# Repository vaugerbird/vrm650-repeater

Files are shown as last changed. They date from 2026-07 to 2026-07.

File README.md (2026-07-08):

# vrm650-repeater

A repository of docs on how to build a DMR repeater using VRM650 radios

### Table of contents:

1. [Parts and materials](./docs/parts.md)
2. [Assembly](./docs/assy.md)
3. [Wiring](./docs/wiring.md)
4. [Configuration](./docs/config.md)
5. [Testing and Tuning](./docs/tune.md)

---

## What this guide is (not):

I am providing this set of instructions as a guideline, not an explicit set of requirements. There are many things I could have done better on and changes or improvements are welcome and encouraged. 

That being said, all materials, instructions, and images here will be following my journey in building a repeater inside of a (very) cheap PC server case from Amazon, while trying to spend the least amount of money possible. Other case/housing configurations can and will work great, but this was the most convenient for me. 

### Begin the guide: [Parts and Materials](/docs/parts.md)

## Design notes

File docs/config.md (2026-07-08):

# Configuration
---
### Previous Page: [Wiring](./wiring.md)
---

## Coming Soon!

---
### Next Page: [Testing and Tuning](./tuning.md)
---

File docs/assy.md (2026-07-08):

# Assembly
---
### Previous Page: [Parts and Materials](./parts.md)
---
This section of the guide will go over how to assemble the repeater into the [2U case](./parts.md/#amazon). This section can be skipped if a different case is used or the radios mounted differently.

---

## Table of contents:
* [Part 0: Tools Needed](#part-0-tools-needed)
* [Part 1: Case Prep](#part-1-case-prep)
* [Part 2: Top Panel Prep](#part-2-top-panel-prep)

---

## Part 0: Tools Needed

Tools required to complete this section, with some examples linked:
* [Medium Sized Locking Pliers](https://www.crescenttool.com/all-tools/wrenches-pliers-drivers/pliers/c10cvn-08-10-curved-jaw-locking-pliers-wire-cutter)
* Hammer
* [Punch](https://www.gearwrench.com/all-tools/hand-tools/striking-struck/82284-14-x-6-starter-punch)
* #1 or #2 Philips Screwdriver
* 3mm Hex Driver
* 2mm Hex Driver
* Drill
* 3/16" HSS Drill Bit

---

## Part 1: Case Prep
1. Start by removing the drive tray from the case, either discarding or saving for another project.
2. Remove the 2 front panel fans with the screws on either side, and save for later.
3. Remove the standoffs in the bottom plate:
    * Grab a standoff with a pair of vice grips, ensuring a firm grip that won't slip.
    * Bend the standoff back and forth, in all directions until loose.
    * Spin the standoff to ensure it is freed from the case.
    * Tap the standoff out the bottom of the case with a hammer.
    * Flatten the metal back out with a hammer and punch.
    * Repeat for all standoffs.
    * **Alternatively**, the standoffs could be drilled out, leaving a cleaner finish but requiring more tools and work.
4. Touch up the paint around the holes with a black paint pen, if desired.
5. Reinstall the 2 front panel fans. 

## Part 2: Top Panel Prep

---
### Next Page: [Wiring](./wiring.md)
---

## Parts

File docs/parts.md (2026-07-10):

# Parts and Materials
---
### Previous Page: [README](../README.md)
---

For this part of the guide, I will break down where I got each part, how many were used, and the general purpose of the part. 

List entries will be formatted as follows:

* Store
  * **Qty.** - Item Name/Model Number
    * Explanation

#### Note: 
If you want to build the exact thing I built, buy (almost) everything on this list!

---

## Table of Contents:
* [eBay](#ebay)
* [Amazon](#amazon)
* [Other Suppliers](#others)
* [3D Printed](#3d-printed-parts)
* [Odds and Ends](#odds-and-ends)
  * [Tools](#odds-and-ends)

---

### eBay
* **2** - [Motorola VRM650](https://www.ebay.com/sch/i.html?_nkw=motorola+F3451A), Model **F3451A** (450-512 MHz)
  * Must be that exact model number, otherwise the radio will be in the 800 MHz range. See [this document](../external/VRMInfo.pdf) for a more in-depth model number list
* **2** - [Motorola HLN6412A Connector](https://www.ebay.com/sch/i.html?_nkw=Motorola+HLN6412A) (Optional)
  * Only required if you want the official connector for this radio, but is pricy and hard to find. I will explain how to use a normal DB25 in [Wiring](./wiring.md).

---

### Amazon
* **Required Radio Parts**
  * **1** - [MaxtonData RLN4008B RIB](https://www.amazon.com/dp/B0F5LFQNLM/)
    * This is __required__ for programming the VRM650/VRM850/MCS2000. RIB-less cables have a low success rate, and do not exist for the VRM series. Alternative RIBs are available for cheaper from other sellers, but this is the one I used and works well for me.
  * **1** - [USB to RS232 Cable](https://www.amazon.com/dp/B006AA04K0/)
    * I used an old Plugable PL2303-based cable, but FTDI-based cables are recommended for reliability, especially on Windows 11. The serial port created by this cable will be passed through to a Windows XP VM, which will be explained in [Configuration](./config.md).
  * **1** - [9V DC Power Supply](https://www.amazon.com/dp/B077XPLH92/) (Optional)
    * This eliminates the need for a 9V battery in the RIB, and feels safer than possibly having a battery die during a program write. 
    * Make sure that the connector is center positive if you use a different supply!
  * **2** - [2-pin SAE Power Cables](https://www.amazon.com/dp/B0DNCM9D2T/)
    * I personally used a different cable from the store I work at, but this is an easier option with a built-in fuse holder. Note the polarity on other cables, the red wire should be on the insulated side of the connector.
    * If using the fuse holder listed later, I would recommend cutting off the built-in fuse holder and crimping new rings.
  * **4** - [DB25 Female Connectors](https://www.amazon.com/dp/B0841FCNJ9/) (Pack of 6)
    * The required quantity changes if the HLN6412A connectors are used. If not using the HLN6412A, 2 connectors will be required to build the Y-cable to connect the MMDVM to the radios.
    * 2 connectors will be required no matter what to build the RIB-to-radio cable.
  * **1** - [DB9 Male Connector](https://www.amazon.com/dp/B09BZ4YZ9R) (Pack of 18(!))
    * Only needed if using the [Repeater Builder STM32_DVM](#others)
  * **~2 ft** - [24 AWG 6P Ribbon Cable](https://www.amazon.com/dp/B099W8RD5K/) (Roll of 5 ft)
    * Only needed if using the [Repeater Builder STM32_DVM](#others). Used for the cables from the MMDVM to the radios.

* **Optional Chasis Parts**
  * **1** - [2U Server PC Case](https://www.amazon.com/dp/B0D41ZJH3D/)
    * This thing is made out of *absolute crap*, but that means it's perfect for chopping up into a repeater housing. "Modifications" required can be found in the [Assembly](./assy.md) page.
  * **1** - [Very Cheap PC Power Supply](https://www.amazon.com/dp/B08FLVGVHN/)
    * This one is a bit strange, I just used this to harvest the rear panel as a filler. I saved the rear panel itself, C14 socket, power switch, and cooling fan. Required PSU butchering can be found in the [Assembly](./assy.md) page.
    * This part could (and should) also be omitted with a 3D printed panel, with features for the C14 socket, switch, and RJ45 panel mount included. 
  * **1** - [Compact 12V Power Supply](https://www.amazon.com/dp/B07WHJF1Q8/)
    * I have not had a chance to test for RFI yet, but this is an actual MEANWELL switching supply, and has good reviews for amateur radio use. 
  * **1** - [6 Position Fuse Holder with Power Rails](https://www.amazon.com/dp/B0838TZ2Z2/)
    * This is how I would recommend everything be connected to power. Everything is protected by a fuse, and power wiring is simplified to a common connection point.
  * **2** - [Type N Panel Mount Connectors](https://www.amazon.com/dp/B09GFMVK2R/) (Pack of 2)
    * These are installed into the I/O shield filler to pass-through the antenna connectors for the RX and TX radios. 
  * **1** - [Type N 90 Degree Adapter](https://www.amazon.com/dp/B07V8MY7SG) (Pack of 2)
    * Used to make clearance for the TX radio later on.
  * **2** - [Type N to Mini UHF Jumper Cable](https://www.amazon.com/dp/B07VDYX6PV/)
    * Required to connect the VRMs to the Type N panel mounts.
  * **2** - [Type N to SO-239](https://www.amazon.com/dp/B083WDV529/) (Pack of 2)
    * Only needed if using PL-259 cables to connect to the repeater.
  * **1** - [PWM Fan Controller with Temp Sensor](https://www.amazon.com/dp/B0GWV4XNXY/) (Pack of 2)
    * Used to automatically ramp up the 80mm fans included with the enclosure when the TX radio warms up.

* **Optional Pi Chassis Parts**
  * **1** - [12V to 5V 5A USB-C Voltage Regulator](https://www.amazon.com/dp/B0CRVW7N2J/)
    * Used for powering the Pi from the 12V power supply.
  * **1** - [USB 3.0 Internal Header to USB A](https://www.amazon.com/dp/B0719J5M9V/)
    * This is only required if you want to pass the front panel USBs to the Raspberry Pi.
  * **1** - [USB-C 90 Degree Adapter](https://www.amazon.com/dp/B0CNGFZ1JD/) (Pack of 2)
    * Required for Pi power connector due to mounting clearance issues.
  * **1** - [Panel Mount RJ45](https://www.amazon.com/dp/B0CFVYJMT2/) (Pack of 2)
    * Required to make the ethernet port accessible on the Pi. I had WiFi reliability issues inside the enclosure.
  * **1** - [1ft SlimRun CAT6A Patch Cable](https://www.amazon.com/dp/B07958SQKS/) (Pack of 5)
    * Connects the panel mount RJ45 to the Pi.

---

## Others
* Raspberry Pi 
  * As everyone knows, electronic prices are insane right now, especially including the Raspberry Pi. I would not recommend anything over the Pi 4, as the Pi 5 is absolute overkill for Pi-Star and would just generate more heat.
  * My recommendations (RAM sizes listed):

    | [Pi 3](https://rpilocator.com/?country=US&cat=PI3) | [Pi 4](https://rpilocator.com/?country=US&cat=PI4) | [Pi Zero](https://rpilocator.com/?country=US&cat=PIZERO2)* |
    |---|---|---|
    | B+ (1 GB)| 1 GB | 2 W |
    | A+ (512 MB) | 2 GB | |

    *The Pi Zero (1st Gen) will not work with newer releases of WPSD and is generally too slow for what is needed. A Pi Zero 2 W is required if using a Zero.
  * The table headers link to rpilocator, which aggrigates stock and prices for different vendors. Click whichever model you're interested in to see stock and prices.

* MMDVM
  * Really only 2 good options exist for repeaters:
    * [Repeater Buildser STM32_DVM](https://www.repeater-builder.com/products/stm32-dvm.html) - $95 + S&H (at time of writing)
    * [ZUM Radio MMDVM-Pi](https://zumradio.com/products.html#mmdvm-pi) - $99.95 + S&H (at time of writing)
  * Personally, I have had *terrible* luck with the MMDVM-Pi and would certainly recommend the STM32_DVM. I used the MMDVM-Pi for my build as I had a semi-broken one left over from another repeater, but prefer working with the STM32_DVM from my experience. This guide will go over setup of both MMDVM options to the best of my ability.

---
## 3D Printed Parts

* **1** - [I/O Shield Filler](../3d-files/IO%20Panel/IOPanel.stl)
  * This is needed to fill the hole where the I/O shield would be on a PC motherboard. The filler has mounting holes for the 2 panel mount Type N connectors.
  * Please excuse the poor 3D model quality, I still am very inexperienced with FreeCAD.

---

## Odds and Ends

These are the random bits and bobs that I used throughout this project.
* Tools:
  * Drill
  * Screwdriver Kit
  * Drill Bit Index
  * Locking Pliers (for pulling standoffs, see [Assembly](./assy.md))
  * Hammer
  * Punch
  * Soldering Iron
  * Die Grinder (for butchering PSU, see [Assembly](./assy.md). Can also be done with tin snips.)
  * Multimeter
  * Terminal Crimper
  * Powerpole Crimper
  * Heat gun
* Hardware:
  * **6** - M4 x 6mm Cap Head Screws (I/O Panel)
  * **4** - M4 x 10mm Cap Head Screws (Power Supply)
  * **4** - M4 x 18mm Cap Head Screws (Fuse Block)
  * **10** - M4 Nuts
  * **14** - M4 Flat Washers
  * **8** - M3 x 8mm FLat Head Hex Screws (Type N Panel Mounts)
  * **8** - M3 Washers 
  * **8** - M3 Nuts
  * **1** - Roll of 1/2" 3M Vehicle Trim Tape (Mounting Radios and 5V Regulator)
  * **A bunch** - Small Zip Ties (Cable Management)
* Electrical:
  * **4** - 12-10 AWG #10 Ring Terminals (Radio Power Cables)
  * **3** - 14-16 AWG #10 Ring Terminals (AC Input Cables)
  * **4** - 22-18 AWG #10 Ring Terminals (5V Regulator and 120mm Fan)
  * **2** - Red 15/30/45A Powerpole Housings (AC Input Cable)
  * **2** - Black 15/30/45A Powerpole Housings (AC Input Cable)
  * **2** - Green 15/30/45A Powerpole Housings (AC Input Cable)
  * **6** - 15A Powerpole Pins (AC Input Cable)
  * **~2 ft** - 16 AWG Black Silicone Wire (AC Input Cable)
  * **~2 ft** - 16 AWG White Silicone Wire (AC Input Cable)
  * **~2 ft** - 16 AWG Green Silicone Wire (AC Input Cable)
  * Solder
  * Asstorted heat shrink for all wires and ring terminals.

---
### Next Page: [Assembly](./assy.md)
---

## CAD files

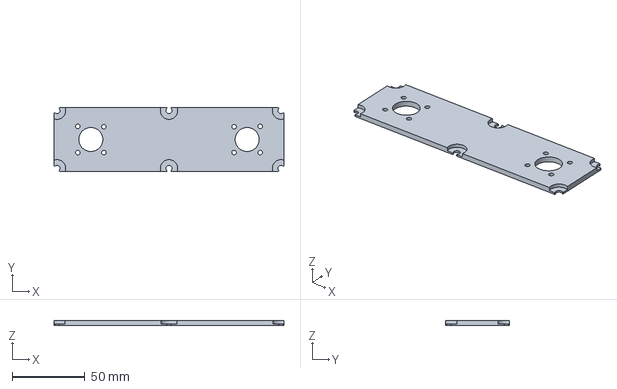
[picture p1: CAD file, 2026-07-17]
3d-files/IO Panel/IOPanel.FCStd
158.5 x 43.9 x 3.30 mm

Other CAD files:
3d-files/IO Panel/IOPanel.stl

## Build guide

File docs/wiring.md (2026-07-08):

# Wiring
---
### Previous Page: [Assembly](./assy.md)
---
This section of the guide will go over how to wire up the various cables and interconnects required to power, program, and control the radios.

---

## Table of Contents
* [Part 0: Tools Required](#part-0-tools-required)
* [Part 1: Power Cables](#part-1-power-cables)
* [Part 2: Programming Cable](#part-2-programming-cable)
* [Part 3: MMDVM Cables](#part-3-mmdvm-cables)
    * [MMDVM-Pi](#mmdvm-pi)
    * [STM32_DVM](#stm32_dvm)
* [Part 4: Front Panel Cables (Optional)](#part-4-front-panel-cables-optional)

---

## Part 0: Tools Required

Tools required to complete this section:
* Wire Strippers (12-18 AWG, 24 AWG)
* Soldering Iron
* Heat Gun or Lighter/Torch
* #0 Philips Screwdriver
* Powerpole Crimper
* Insulated Terminal Crimper

---

## Part 1: Power Cables

---

## Part 2: Programming Cable

Parts required:
* **2** - DB25 Female Connectors
* Any length of 5 (or more) conductor cable
    * I used an old chunk of CAT5 and used 5 of the 8 conductors. Really anything should work well for what we're doing.

#### Assembly Steps
1. Before beginning soldering, take the DB25 for the VRM and bend the side tabs toward the back of the connector. This is required to make the connector fit into the body of the radio.
    * [Image here]
2. Solder the cable to both connectors following the schematic, with connected pin numbers in the table:

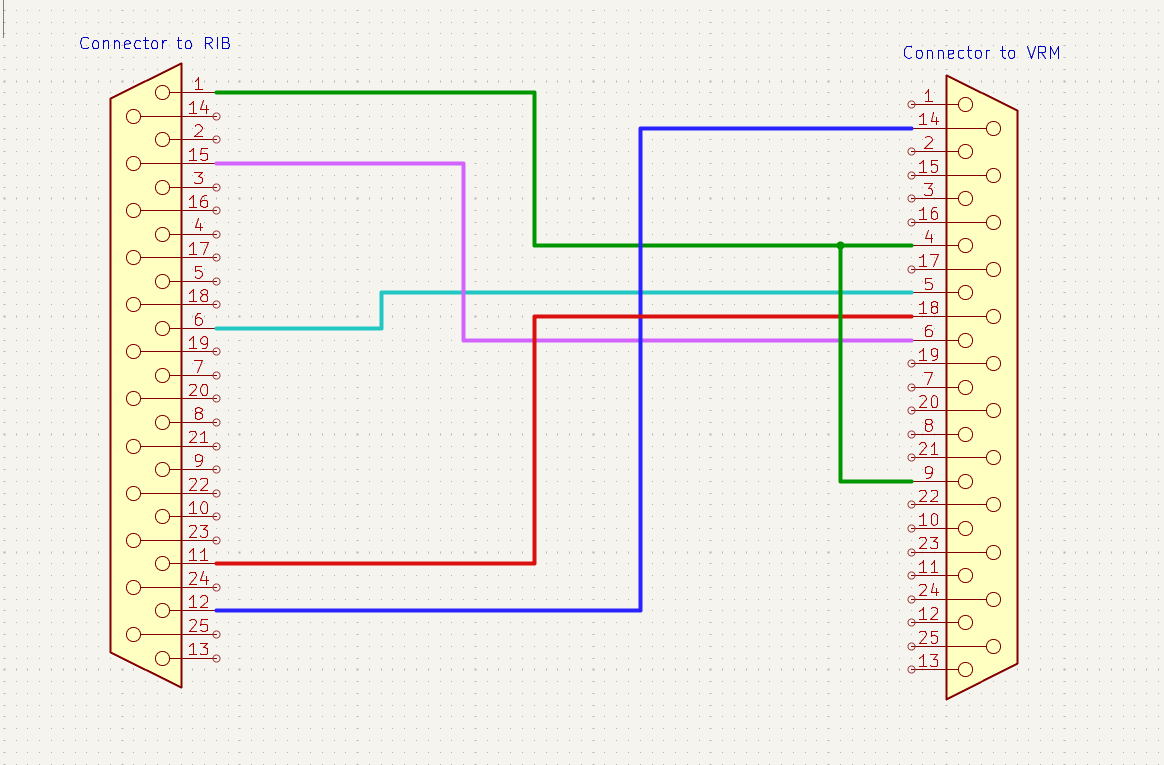
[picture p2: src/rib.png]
Schematic of VRM650 RIB cable
    

    | RIB Connector | VRM Connector | Sch. Color |
    |---|---|---|
    | Pin 1 | Pins 4 & 9 | Green |
    | Pin 6 | Pin 5 | Teal |
    | Pin 11 | Pin 18 | Red |
    | Pin 12 | Pin 14 | Blue |
    | Pin 15 | Pin 6 | Magenta |

    **Note**: Make sure pins 4 and 9 are connected to eachother on the VRM side, otherwise the radio will enter emergency mode and will not respond to input.

---

## Part 3: MMDVM Cables

As there are multiple options for wiring up the MMDVM, this part will be split into two parts, one for the [MMDVM-Pi](#mmdvm-pi), and one for the [STM32_DVM](#stm32_dvm).

Parts required:
* **2** - DB25 Female Connectors
* For MMDVM-Pi:
    * **1** - Included Interface Cable
* For STM32_DVM:
    * **~2 ft** - 6 Conductor Ribbon Cable
    * **1** - DB9 Male Connector with Housing

#### MMDVM-Pi

1. Follow [Step 1 in Part 2](#assembly-steps) with 2 of the DB25 connectors, one for the RX radio and one for the TX radio.
2. Using the cable provided with the MMDVM-Pi, follow the schematic shown to connect the DB25 connectors. Connected pin numbers are in the table. Make sure pins 4 and 9 are connected together on each connector.
    
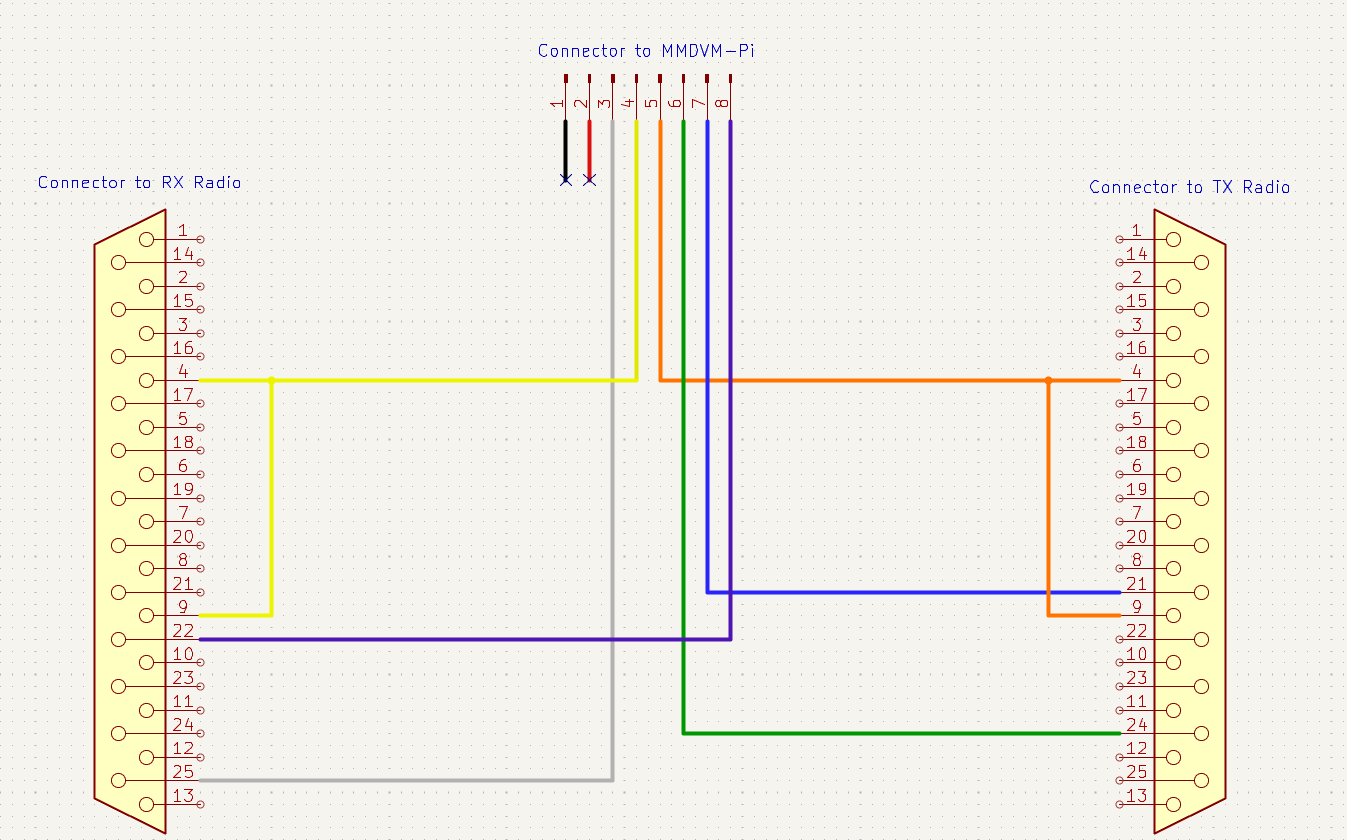
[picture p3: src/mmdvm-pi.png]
Schematic of VRM650 to MMDVM-Pi cable
    

    | MMDVM-Pi | RX Radio | TX Radio | Pin Disc. | Wire Color |
    |---|---|---|---|---|
    | Pin 1 | N/C | N/C | CTRL | Black |
    | Pin 2 | N/C | N/C | COS | Red |
    | Pin 3 | Pin 25 |  | RX Audio | White |
    | Pin 4 | Pins 4 & 9 |  | Ground | Yellow |
    | Pin 5 |  | Pins 4 & 9 | Ground | Orange |
    | Pin 6 |  | Pin 24 | TX Audio | Green |
    | Pin 7 |  | Pin 21 | PTT | Blue |
    | Pin 8 | Pin 22 |  | RSSI | Purple |

#### STM32_DVM

1. Follow [Step 1 in Part 2](#assembly-steps) with 2 of the DB25 connectors, one for the RX radio and one for the TX radio.
2. Using the piece of ribbon cable and the DB9 male connector from the parts list, follow the schematic shown to connect the DB25 connectors. Connected pin numbers are in the table. Make sure pins 4 and 9 are connected together on each connector.
    
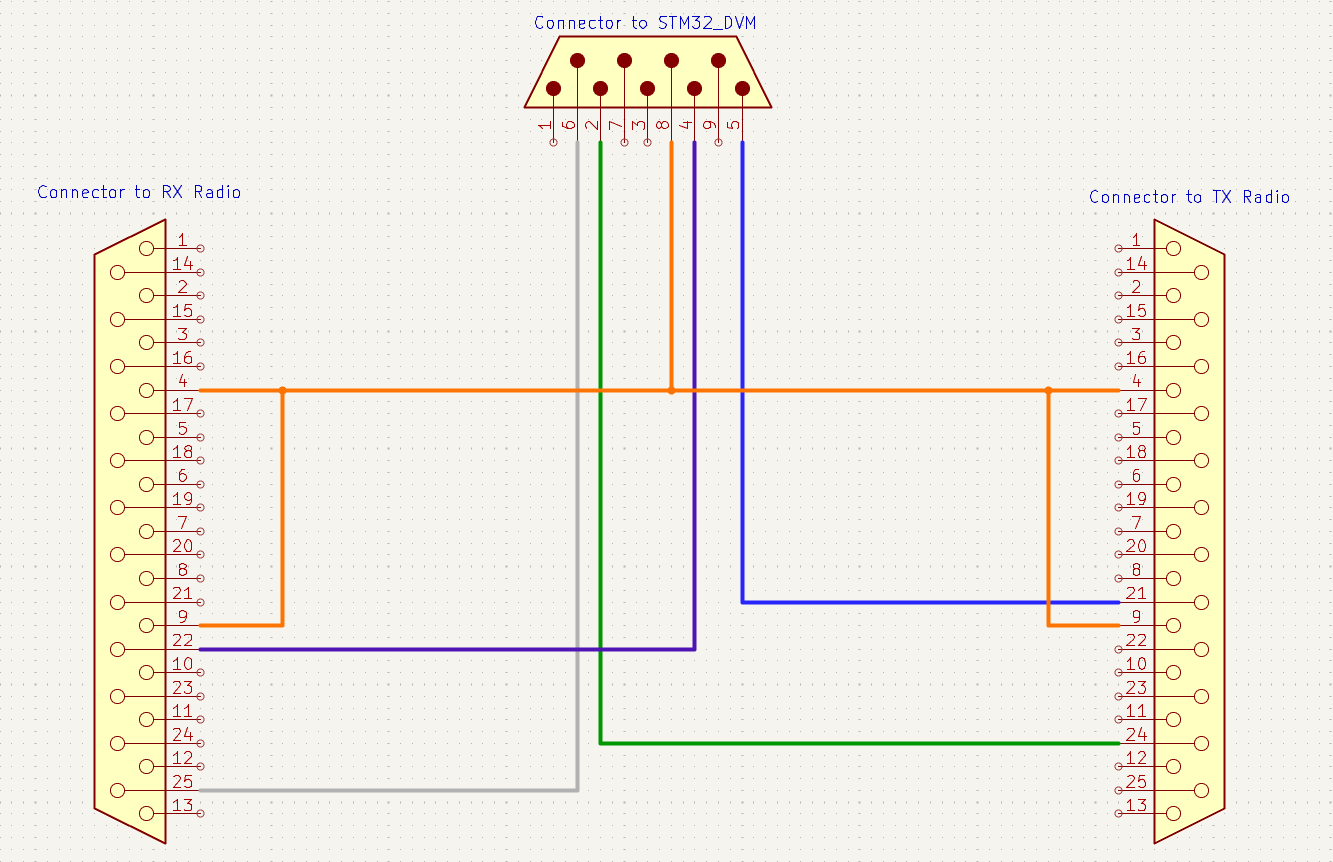
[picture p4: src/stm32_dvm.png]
    

    | STM32_DVM | RX Radio | TX Radio | Pin Disc. | Sch. Color |
    |---|---|---|---|---|
    | Pin 1 | | | N/C | N/A |
    | Pin 2 | | Pin 24 | TX Audio | Green |
    | Pin 3 | N/C | N/C | Inhibit | N/A |
    | Pin 4 | Pin 22 |  | RSSI | Purple |
    | Pin 5 |  | Pin 21 | PTT | Blue |
    | Pin 6 | Pin 25 |  | RX Audio | Grey |
    | Pin 7 | | | N/C | N/A |
    | Pin 8 | Pins 4 & 9 | Pins 4 & 9 | Ground | Orange |
    | Pin 9 | N/C | N/C | VIN | N/A |

---

## Part 4: Front Panel Cables (Optional)

---
### Next Page: [Configuration](./config.md)
---

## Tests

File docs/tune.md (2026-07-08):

# Testing and Tuning
---
### Previous Page: [Configuration](./config.md)
---
## Coming Soon!

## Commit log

2026-07-08 Add attempt at 3D modeling w/o Inventor
    [IOPanel.FCStd, IOPanel.stl]
2026-07-08 Update 3D files and parts.md to match
    [IOPanel.FCStd, IOPanel.stl]
2026-07-08 Get started on assembly and wiring pages
2026-07-08 Add MMDVM wiring instructions
2026-07-10 Clean up 3D model for IO Panel
    [IOPanel.FCStd, IOPanel.stl]
2026-07-10 Export entire stl
    [IOPanel.FCStd, IOPanel.stl]
2026-07-17 Fix washer boss thickness
    [IOPanel.FCStd, IOPanel.stl]
